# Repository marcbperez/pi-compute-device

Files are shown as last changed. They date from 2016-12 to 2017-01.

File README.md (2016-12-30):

# pi-compute-device

A portable device built with the Raspberry Pi Compute module.

## Installation

The schematics project is done in KiCad, free and available to most common
platforms. More information on how to download and install KiCad can be found in
its [official download page][download-kicad].

## Usage

Clone the sources and browse the package folder. The KiCad project is located in
`kicad-project/pi-compute-device.pro`.

```bash
git clone https://github.com/marcbperez/pi-compute-device
cd pi-compute-device
```

## Testing

There is no testing in place for this project yet.

## Troubleshooting

The [issue tracker][issue-tracker] intends to manage and compile bugs,
enhancements, proposals and tasks. Reading through its material or reporting to
its contributors via the platform is strongly recommended.

## Contributing

This project adheres to [Semantic Versioning][semver] and to certain syntax
conventions defined in [.editorconfig][editorconfig]. To get a list of changes
refer to the [CHANGELOG][changelog]. Only branches prefixed by *feature-*,
*hotfix-*, or *release-* will be considered:

  - Fork the project.
  - Create your new branch: `git checkout -b feature-my-feature develop`
  - Commit your changes: `git commit -am 'Added my new feature.'`
  - Push the branch: `git push origin feature-my-feature`
  - Submit a pull request.

## Credits

This project is created by [marcbperez][author] and maintained by its
[author][author] and contributors.

## License

This project is licensed under the [Apache License Version 2.0][license].

[author]: https://marcbperez.github.io
[issue-tracker]: https://github.com/marcbperez/pi-compute-device/issues
[editorconfig]: .editorconfig
[changelog]: CHANGELOG.md
[license]: LICENSE
[semver]: http://semver.org
[download-kicad]: http://kicad-pcb.org/download/

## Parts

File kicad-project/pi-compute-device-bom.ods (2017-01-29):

Item | Quantity | Reference | Voltage | Current | Power | Material | Size | Tolerance | Manufacturer | Manuf. Part No | Description
1 | 4 | C10,C11,C14,C15 | 6.3V |  |  | X7R | 2012 | 20% | Generic | Generic | CAP, CHIP, 2012, 10u, 20%, 6.3V
2 | 6 | C8,C1,C13,C2 | 6.3V |  |  | X7R | 3216 | 20% | Generic | Generic | CAP, CHIP, 3216, 47u, 20%, 6.3V
3 | 3 | C5,C16,C18 | 6.3V |  |  | X7R | 1005 | 10% | Generic | Generic | CAP, CHIP, 1005, 1u, 10%, 6.3V
4 | 1 | C7 | 6.3V |  |  | X7R | 1608 | 20% | Generic | Generic | CAP, CHIP, 1608, 4.7u, 20%, 6.3V
5 | 5 | C9,C6,C19,C20 | 6.3V |  |  | X7R | 1005 | 10% | Generic | Generic | CAP, CHIP, 1005, 100n, 10%, 6.3V
6 | 2 | C3,C12 |  |  |  |  | 1005 |  | Generic | Generic | CAP, CHIP, 1005
7 | 1 | D1 |  |  |  |  | 1608 |  | Generic | Generic | LED, SMT, 1608, RED
8 | 1 | D2 |  |  |  |  | 1608 |  | Generic | Generic | LED, SMT, 1608, GREEN
9 | 1 | F1 | 6V | 2.0A |  |  |  |  | Bourns | MF-MSMF200 | Polyfuse, 2.0A hold, 4.0A trip
10 | 1 | P5 |  |  |  |  |  |  | TE | 1473005-4 | DDR2 SODIMM Socket
11 | 2 | P1, P4 |  |  |  |  |  |  | FCI | 10103594-0001LF | Socket, uUSB, B, RA, PTH/SMT
12 | 1 | P3 |  |  |  |  |  |  | Generic | Generic | 3W 0.1" pin header single row
13 | 2 | P6,P7 |  |  |  |  |  |  | Generic | Generic | 60W 0.1" pin header (2 rows x30)
16 | 1 | J1 |  |  |  |  |  |  | FCI | 10029449-111RLF | HDMI Con, RA, SMT with PTH lugs
18 | 2 | L1,L2 |  | 2A |  |  | 4x4mm | 20% | Bourns | SRN4018-4R7M | Semi shielded power inductor, 4.7uH, Isat=2A, Irma=1.9A, R=84mR
19 | 5 | Q1,Q2,Q3,Q4 |  |  |  |  |  |  | Diodes Inc | DMG1012T | MOSFET, N, LOW VT, LOGIC
20 | 7 | R2,R7,R3,R8,R15,R19 |  |  | 0.1W |  | 2012 | 1% | Generic | Generic | RES, CHIP, 2012, 1%, 0.25W 0R
21 | 6 | R6,R23,R12,R13,R21,R22 |  |  | 63mW |  | 1005 | 1% | Generic | Generic | RES, CHIP, 1005, 100K, 1%, 0.063W
22 | 2 | R4,R14 |  |  | 63mW |  | 1005 | 1% | Generic | Generic | RES, CHIP, 1005, 470R, 1%, 0.063W
23 | 4 | R18,R17,R16 |  |  | 63mW |  | 1005 | 1% | Generic | Generic | RES, CHIP, 1005, 47K, 1%, 0.063W
24 | 1 | R24 |  |  | 63mW |  | 1005 | 1% | Generic | Generic | RES, CHIP, 1005, 1K, 1%, 0.063W
26 | 1 | R20 |  |  | 63mW |  | 1005 | 1% | Generic | Generic | RES, CHIP, 1005, 27K, 1%, 0.063W
27 | 1 | R5 |  |  |  |  | 1005 |  | Generic | Generic | RES, CHIP, 1005, 0R
28 | 1 | R9 |  |  |  |  | 1005 |  | Generic | Generic | RES, CHIP, 1005, 0R
29 | 1 | U2 |  |  |  |  |  |  | Diodes | PAM2306AYPKE | IC, SMT, Dual SMPS, V1=3V3, V2=1V8
30 | 1 | U1 |  |  |  |  | SOT323 |  | Diodes Inc | AP7115-25SEG-7 | IC, LDO, 2.5V, 150mA SOT-25
31 | 1 | U3 |  |  |  |  |  |  | Diodes | AP2331W | Current limited load switch, 200mA
32 | 1 | U4 |  |  |  |  |  |  | ON Semiconductor | ESD5384 | IC, ESD, HDMI CONTROL
34 | 2 | R10,R11 |  |  |  |  |  |  | Generic | Generic | RES, CHIP, 1005
35 | 1 | P2 |  |  |  |  |  |  | Generic | Generic | 2x3W 0.1" pin header (2 rows x3)
36 | 3 | SHUNT/JUMPER |  |  |  |  |  |  | Generic | Generic | 2x shunt fitted to J3 (3V3) and J4 (EN)

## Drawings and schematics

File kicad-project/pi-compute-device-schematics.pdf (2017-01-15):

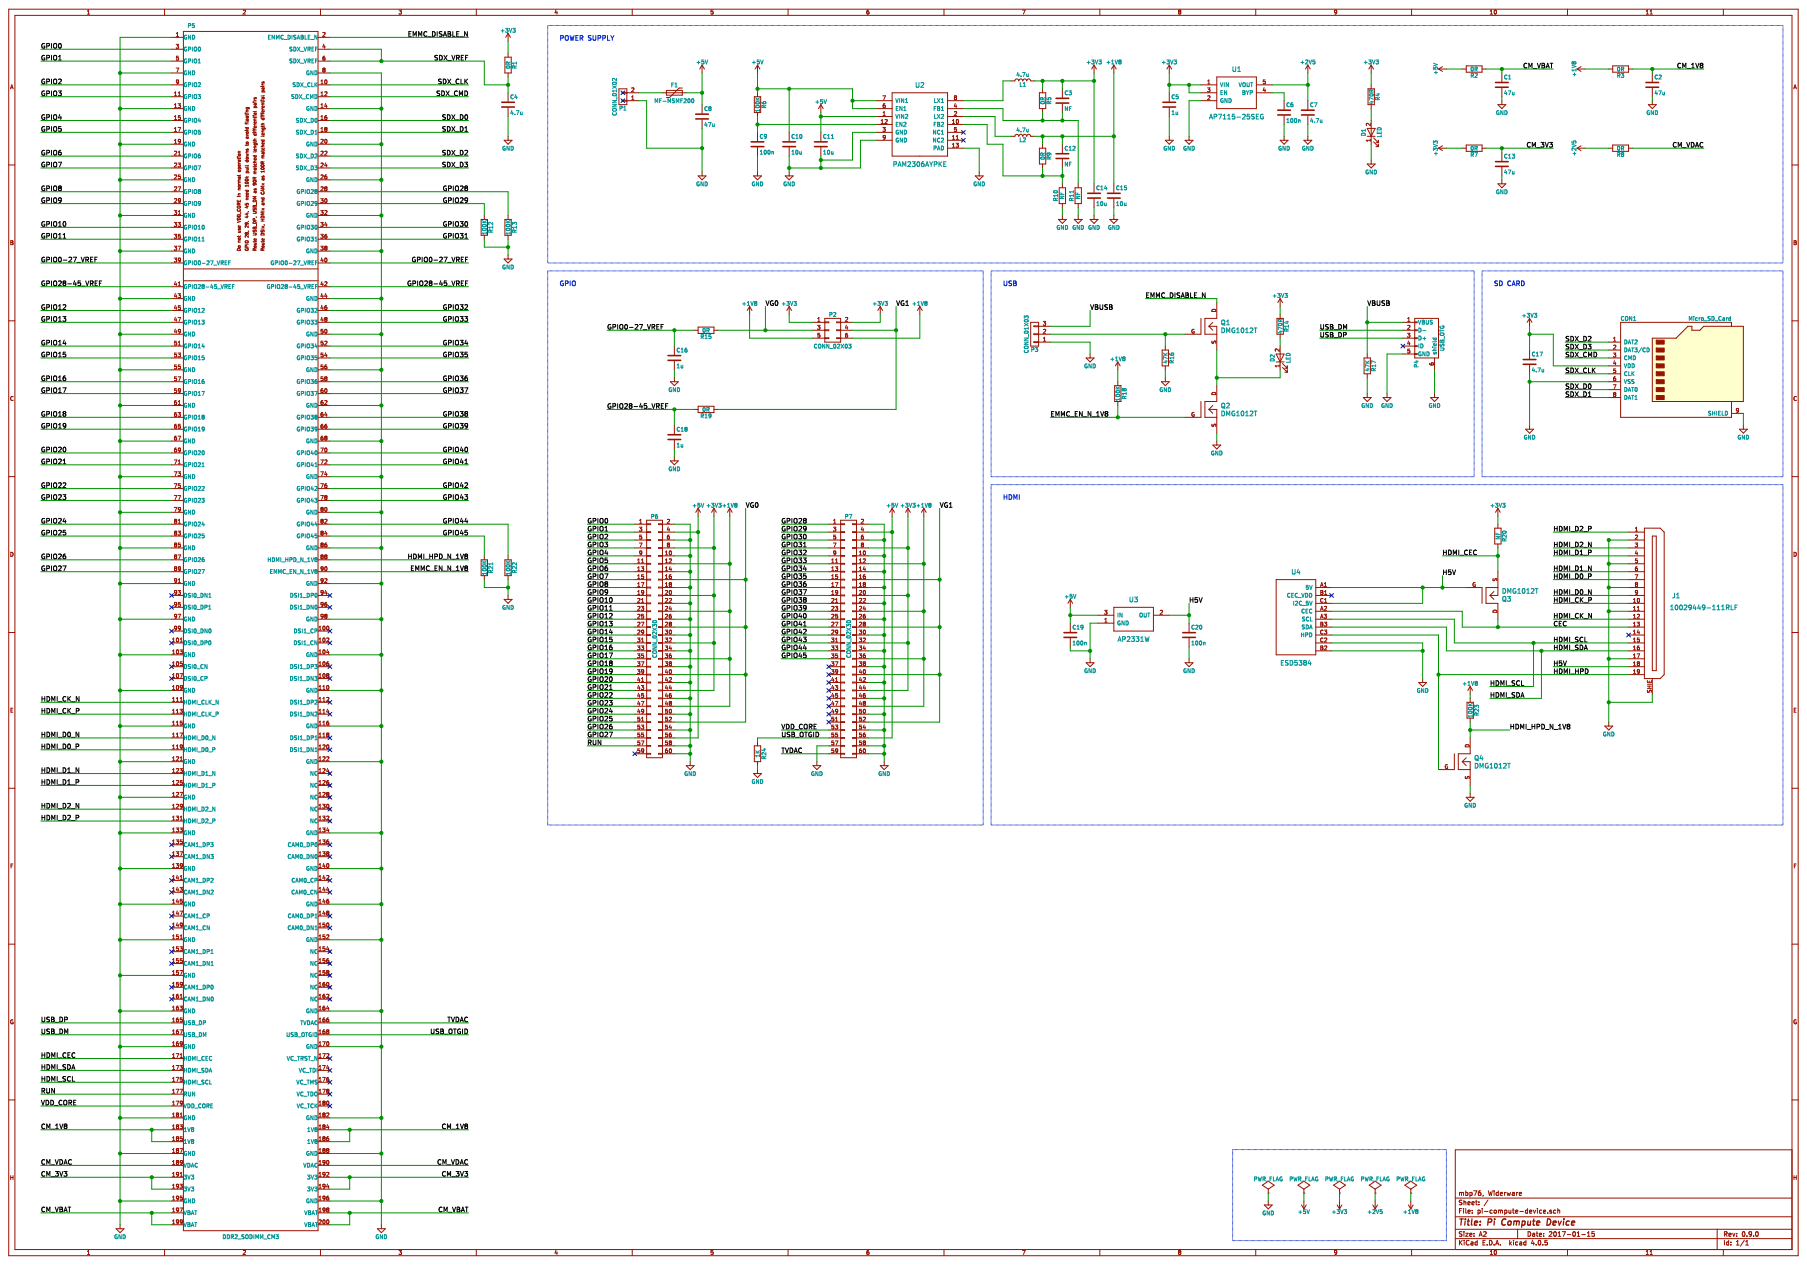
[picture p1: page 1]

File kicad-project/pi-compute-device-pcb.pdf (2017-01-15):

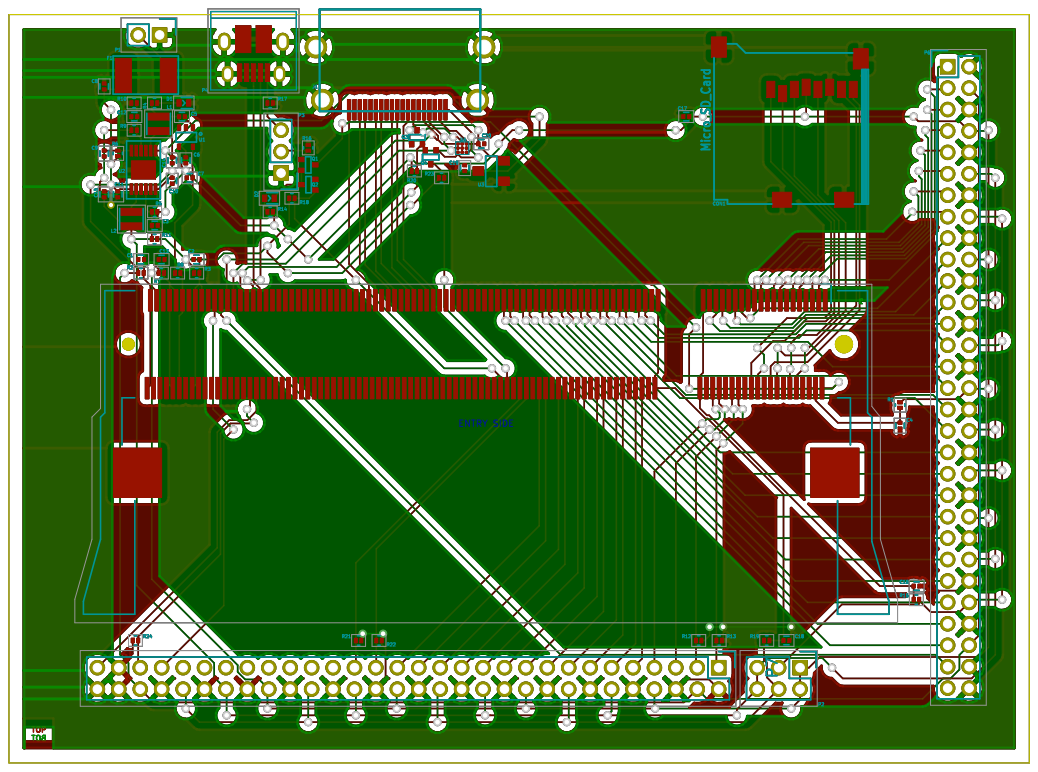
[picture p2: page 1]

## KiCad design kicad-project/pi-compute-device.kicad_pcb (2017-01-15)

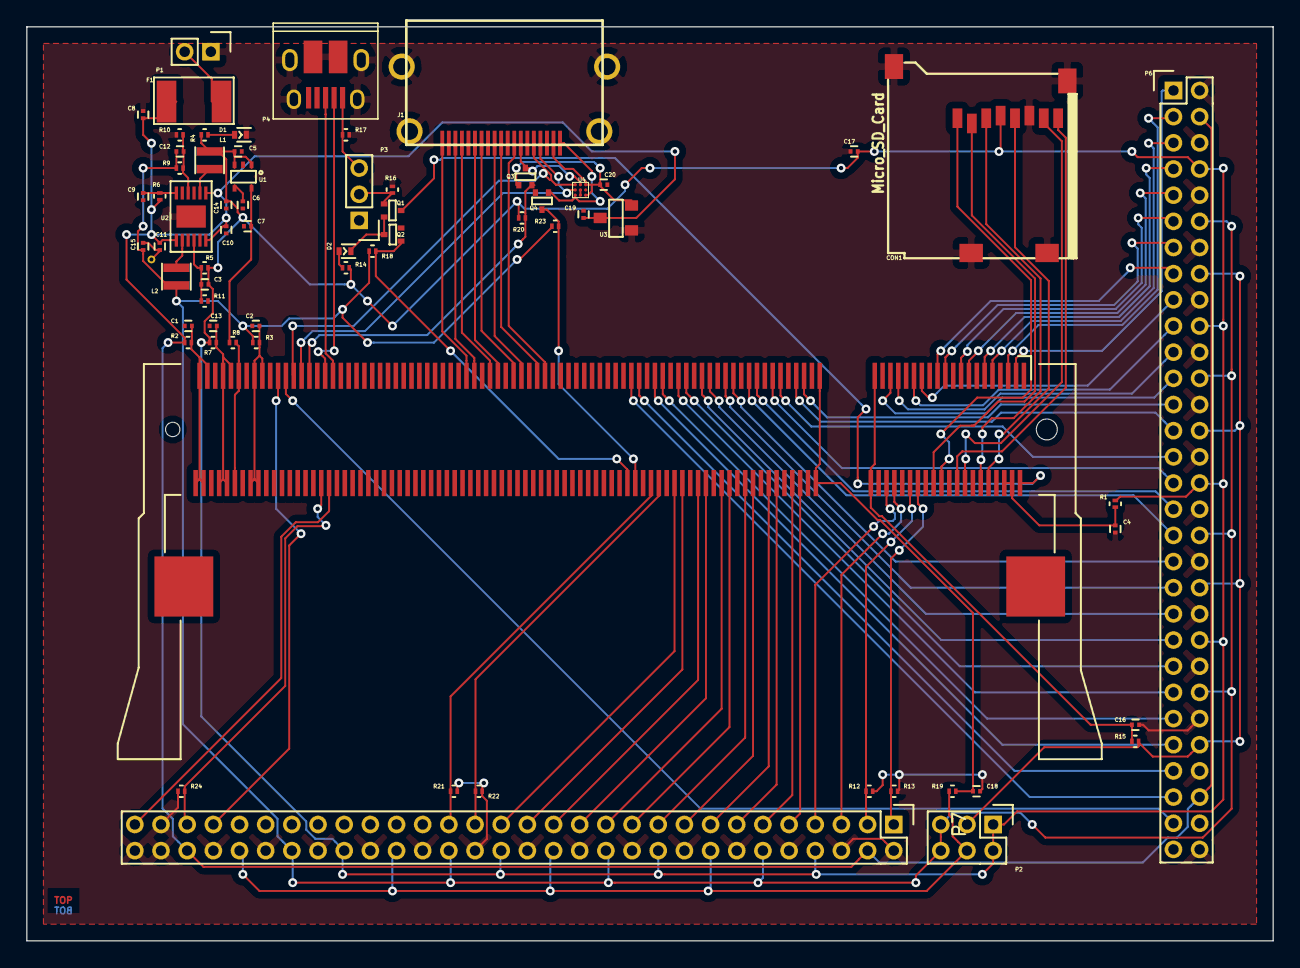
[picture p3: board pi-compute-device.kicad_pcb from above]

Board: 2 copper layers, 95.2 x 69.8 mm, 66 parts (0 on the bottom side), 101 nets.

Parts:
C1, C2, C8, C13: 47u; C_0201
C3, C12: NF; C_0201
C4, C7, C17: 4.7u; C_0201
C5, C16, C18: 1u; C_0201
C6, C9, C19, C20: 100n; C_0201
C10, C11, C14, C15: 10u; C_0201
CON1: Micro_SD_Card; 2908-05WB-MG
D1, D2: LED; LED_0402
F1: MF-MSMF200
J1: 47151-1051; 10029449-111RLF
L1, L2: 4.7u; Inductor_Taiyo-Yuden_MD-2020
P1: CONN_01X02; Pin_Header_Straight_1x02_Pitch2.00mm
P2: CONN_02X03; Pin_Header_Straight_2x03_Pitch2.00mm
P3: CONN_01X03; Pin_Header_Straight_1x03_Pitch2.00mm
P4: USB_OTG; 10103594-0001LF
P5: DDR2_SODIMM_CM3; 1473005
P6, P7: CONN_02X30; Pin_Header_Straight_2x30_Pitch2.00mm
Q1, Q2, Q3, Q4: DMG1012T
R1, R2, R3, R5, R7, R8, R9, R15, R19: 0R; R_0201
R4, R14: 470R; R_0201
R6, R12, R13, R18, R21, R22, R23: 100K; R_0201
R10, R11, R20: NF; R_0201
R16, R17: 47K; R_0201
R24: 1K; R_0201
U1: AP7115-25SEG
U2: PAM2306AYPKE
U3: AP2331W
U4: ESD5384

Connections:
+1V8: C12.1, C15.1, L2.2, P2.5, P2.6, P6.12, P6.24, P6.36, P6.48, P7.12, P7.24, P7.36, P7.48, R3.2, R9.1, R18.1, R23.1
+2V5: C7.1, R8.2, U1.5
+3V3: C3.1, C5.1, C14.1, C17.1, CON1.4, L1.2, P2.1, P2.2, P6.8, P6.20, P6.32, P6.44, P7.8, P7.20, P7.32, P7.44, R1.1, R4.1, R5.1, R7.2, R14.1, R20.1, U1.1, U1.3
+5V: C8.1, C10.1, C11.1, C19.1, F1.1, P6.4, P6.56, P7.4, P7.56, R2.2, R6.1, U2.1, U2.6, U2.7, U3.3
/CEC: J1.13, Q3.D, U4.A2
/CM_1V8: C2.1, P5.183, P5.184, P5.185, P5.186, R3.1
/CM_3V3: C13.1, P5.191, P5.192, P5.193, P5.194, R7.1
/CM_VBAT: C1.1, P5.197, P5.198, P5.199, P5.200, R2.1
/CM_VDAC: P5.189, P5.190, R8.1
/EMMC_DISABLE_N: P5.2, Q1.D
/EMMC_EN_N_1V8: P5.90, Q2.G, R18.2
/GPIO0: P5.3, P6.1
/GPIO0-27_VREF: C16.1, P5.39, P5.40, R15.2
/GPIO1: P5.5, P6.3
/GPIO2: P5.9, P6.5
/GPIO3: P5.11, P6.7
/GPIO4: P5.15, P6.9
/GPIO5: P5.17, P6.11
/GPIO6: P5.21, P6.13
/GPIO7: P5.23, P6.15
/GPIO8: P5.27, P6.17
/GPIO9: P5.29, P6.19
/GPIO10: P5.33, P6.21
/GPIO11: P5.35, P6.23
/GPIO12: P5.45, P6.25
/GPIO13: P5.47, P6.27
/GPIO14: P5.51, P6.29
/GPIO15: P5.53, P6.31
/GPIO16: P5.57, P6.33
/GPIO17: P5.59, P6.35
/GPIO18: P5.63, P6.37
/GPIO19: P5.65, P6.39
/GPIO20: P5.69, P6.41
/GPIO21: P5.71, P6.43
/GPIO22: P5.75, P6.45
/GPIO23: P5.77, P6.47
/GPIO24: P5.81, P6.49
/GPIO25: P5.83, P6.51
/GPIO26: P5.87, P6.53
/GPIO27: P5.89, P6.55
/GPIO28: P5.28, P7.1, R13.1
/GPIO28-45_VREF: C18.1, P5.41, P5.42, R19.2
/GPIO29: P5.30, P7.3, R12.1
/GPIO30: P5.34, P7.5
/GPIO31: P5.36, P7.7
/GPIO32: P5.46, P7.9
/GPIO33: P5.48, P7.11
/GPIO34: P5.52, P7.13
/GPIO35: P5.54, P7.15
/GPIO36: P5.58, P7.17
/GPIO37: P5.60, P7.19
/GPIO38: P5.64, P7.21
/GPIO39: P5.66, P7.23
/GPIO40: P5.70, P7.25
/GPIO41: P5.72, P7.27
/GPIO42: P5.76, P7.29
/GPIO43: P5.78, P7.31
/GPIO44: P5.82, P7.33, R22.1
/GPIO45: P5.84, P7.35, R21.1
/H5V: C20.1, J1.18, Q3.G, U3.2, U4.A1, U4.C1
/HDMI_CEC: P5.171, Q3.S, R20.2
/HDMI_CK_N: J1.12, P5.111
/HDMI_CK_P: J1.10, P5.113
/HDMI_D0_N: J1.9, P5.117
/HDMI_D0_P: J1.7, P5.119
/HDMI_D1_N: J1.6, P5.123
/HDMI_D1_P: J1.4, P5.125
/HDMI_D2_N: J1.3, P5.129
/HDMI_D2_P: J1.1, P5.131
/HDMI_HPD: J1.19, Q4.G, U4.C3
/HDMI_HPD_N_1V8: P5.88, Q4.D, R23.2
/HDMI_SCL: J1.15, P5.175, U4.A3
/HDMI_SDA: J1.16, P5.173, U4.B3
/RUN: P5.177, P6.57
/SDX_CLK: CON1.5, P5.10
/SDX_CMD: CON1.3, P5.12
/SDX_D0: CON1.7, P5.16
/SDX_D1: CON1.8, P5.18
/SDX_D2: CON1.1, P5.22
/SDX_D3: CON1.2, P5.24
/SDX_VREF: C4.1, P5.4, P5.6, R1.2
/TVDAC: P5.166, P7.59
/USB_DM: P4.2, P5.167
/USB_DP: P4.3, P5.165
/USB_OTGID: P5.168, P7.55, R24.1
/VBUSB: P3.3, P4.1, R17.1
/VDD_CORE: P5.179, P7.53
/VG0: P2.3, P6.16, P6.28, P6.40, P6.52, R15.1
/VG1: P2.4, P7.16, P7.28, P7.40, P7.52, R19.1
GND: C1.2, C2.2, C4.2, C5.2, C6.2, C7.2, C8.2, C9.2, C10.2, C11.2, C13.2, C14.2, C15.2, C16.2, C17.2, C18.2, C19.2, C20.2, CON1.6, CON1.9, D1.1, J1.2, J1.5, J1.8, J1.11, J1.17, J1.SHIE, P1.1, P3.1, P4.5, P4.6, P5.1, P5.7, P5.8, P5.13, P5.14, P5.19, P5.20, P5.25, P5.26, P5.31, P5.32, P5.37, P5.38, P5.43, P5.44, P5.49, P5.50, P5.55, P5.56, P5.61, P5.62, P5.67, P5.68, P5.73, P5.74, P5.79, P5.80, P5.85, P5.86, P5.91, P5.92, P5.97, P5.98, P5.103, P5.104, P5.109, P5.110, P5.115, P5.116, P5.121, P5.122, P5.127, P5.133, P5.134, P5.139, P5.140, P5.145, P5.146, P5.151, P5.152, P5.157, P5.163, P5.164, P5.169, P5.170, P5.181, P5.182, P5.187, P5.188, P5.195, P5.196, P6.2, P6.6, P6.10, P6.14, P6.18, P6.22, P6.26, P6.30, P6.34, P6.38, P6.42, P6.46, P6.50, P6.54, P6.58, P6.60, P7.2, P7.6, P7.10, P7.14, P7.18, P7.22, P7.26, P7.30, P7.34, P7.38, P7.42, P7.46, P7.50, P7.54, P7.57, P7.58, P7.60, Q2.S, Q4.S, R10.1, R11.1, R12.2, R13.2, R16.2, R17.2, R21.2, R22.2, R24.2, U1.2, U2.3, U2.9, U2.13, U3.1, U4.B2, U4.C2
unnamed: C3.2, R5.2, R11.2, U2.4
unnamed: C6.1, U1.4
unnamed: C9.1, R6.2, U2.12
unnamed: C12.2, R9.2, R10.2, U2.10
unnamed: D1.2, R4.2
unnamed: D2.1, Q1.S, Q2.D
unnamed: D2.2, R14.2
unnamed: F1.2, P1.2
unnamed: L1.1, U2.8
unnamed: L2.1, U2.2
unnamed: P3.2, Q1.G, R16.1

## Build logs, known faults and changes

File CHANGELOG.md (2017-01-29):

# Change Log

All notable changes to this project will be documented in this file. This
project adheres to [Semantic Versioning](http://semver.org).

## 0.17.0 - 2017-01-29

### Added

  - Project bill of materials.

## 0.16.0 - 2017-01-15

### Added

  - 2908-05WB-MG datasheet and footprint.
  - 10029449-111RLF datasheet and footprint.
  - 10103594-0001LF datasheet and footprint.
  - Schematics and board layout preview PDFs.
  - First partially routed board.
  - Project netlist.
  - Stitch footprint for layer stitching.

### Changed

  - 10029449-111RLF as default HDMI connector.
  - Main project and schematics with new libraries and addons.
  - PAM2306AYPKE and MF-MSMF200 components.
  - Git ignore list with new files.

## 0.15.0 - 2017-01-14

### Added

  - PAM2306AYPKE component footprint and library.
  - PAM2306AYPKE component datasheet.

## 0.14.0 - 2017-01-13

### Added

  - ESD5384 component footprint and library.
  - ESD5384 component datasheet.

## 0.13.0 - 2017-01-12

### Added

  - DMG1012T component footprint and library.
  - DMG1012T component datasheet.

## 0.12.0 - 2017-01-11

### Added

  - AP7115-25SEG component footprint and library.
  - AP7115-25SEG component datasheet.

## 0.11.0 - 2017-01-10

### Added

  - AP2331W component footprint and library.
  - AP2331W component datasheet.

## 0.10.0 - 2017-01-08

### Added

  - 1473005 component footprint and library.
  - 1473005 component datasheet.

## 0.9.0 - 2017-01-07

### Added

  - MF-MSMF200 component footprint and library.
  - MF-MSMF200 component datasheet.

## 0.8.0 - 2017-01-06

### Changed

  - DMG1012T pin names for main component.
  - DMG1012T pin reference on schematics.
  - Project information for DMG1012T.

## 0.7.0 - 2017-01-05

### Added

  - HDMI module to schematics.
  - Library for AP2331W.
  - Library for ESD5384.
  - Library for 47151-1051.

## 0.6.0 - 2017-01-04

### Added

  - Micro SD Card module to schematics.

## 0.5.0 - 2017-01-03

### Added

  - USB module to schematics.
  - Library for DMG1012T.

## 0.4.0 - 2017-01-02

### Added

  - GPIO module to schematics.

## 0.3.0 - 2016-12-31

### Added

  - Power supply module to schematics.
  - Library for PAM2306AYPKE.
  - Library for AP7115-25SEG.

## 0.2.0 - 2016-12-30

### Added

  - Schematics project with DDR2 SODIMM connector for CM3.
  - Library for DDR2 SODIMM connector for CM3.

### Fixed

  - Small typographical errors on the README file.

## 0.1.0 - 2016-12-29

### Added

  - A README which covers project description and usage.
  - This CHANGELOG file to document project changes and versions.
  - An EditorConfig to suggest syntax and format standards.
  - A LICENSE file to define project ownership and rights.
  - A .gitignore list for untracked resources.

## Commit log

2016-12-30 Added schematics project with DDR2 SODIMM connector for CM3.
    [pi-compute-device.sch]
2016-12-30 Added library for DDR2 SODIMM connector for CM3.
2016-12-31 Added power supply module to schematics.
    [pi-compute-device.sch]
2017-01-02 Added GPIO module to schematics.
    [pi-compute-device.sch]
2017-01-03 Added USB module to schematics.
    [pi-compute-device.sch]
2017-01-04 Added Micro SD Card module to schematics.
    [pi-compute-device.sch]
2017-01-05 Added HDMI module to schematics.
    [pi-compute-device.sch]
2017-01-06 Changed DMG1012T pin names for main component.
2017-01-06 Changed DMG1012T pin references on schematics.
    [pi-compute-device.sch]
2017-01-06 Bumped version to 0.8.0.
    [pi-compute-device.sch]
2017-01-07 Added MF-MSMF200 component footprint and library.
2017-01-08 Added 1473005 component footprint and library.
2017-01-10 Added AP2331W component footprint and library.
2017-01-11 Added AP7115-25SEG component footprint and library.
2017-01-12 Added DMG1012T component footprint and library.
2017-01-13 Added ESD5384 component footprint and library.
2017-01-14 Added PAM2306AYPKE component footprint and library.
2017-01-15 Added 2908-05WB-MG datasheet and footprint.
2017-01-15 Added 10029449-111RLF datasheet and footprint.
2017-01-15 Added 10103594-0001LF datasheet and footprint.
2017-01-15 Added Schematics and board layout preview PDFs.
2017-01-15 Added first partially routed board.
    [pi-compute-device.kicad_pcb]
2017-01-15 Changed 10029449-111RLF as default HDMI connector.
2017-01-15 Main project and schematics with new libraries and addons.
    [pi-compute-device.sch]
2017-01-15 Added stitch footprint for layer stitching.
2017-01-29 Added project bill of materials.
    [pi-compute-device-bom.ods]
